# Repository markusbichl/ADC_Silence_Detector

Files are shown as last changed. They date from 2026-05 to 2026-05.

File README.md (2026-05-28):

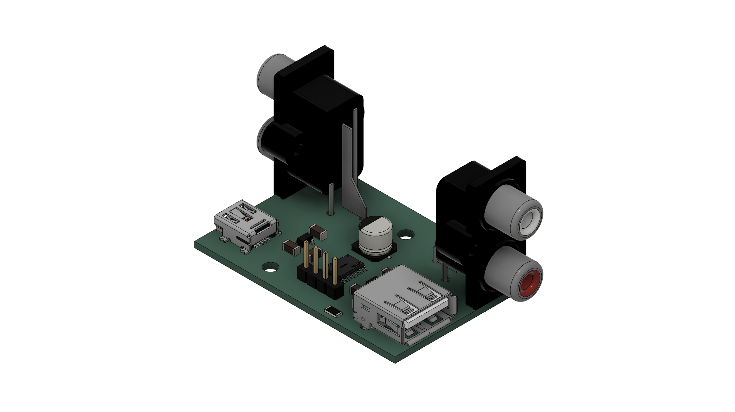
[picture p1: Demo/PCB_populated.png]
PCB populated render ADC Silence Detector PCB populated rendered


# ADC Silence Detector

A compact embedded device that monitors analog audio input and automatically cuts power to a downstream USB ADC when silence is detected - eliminating idle noise and unnecessary power draw.

---

## Overview

The ADC Silence Detector sits inline between your audio source and your USB ADC. It continuously monitors the analog audio signal on both left and right channels. As long as audio is present, the USB-A output port stays powered. Once silence is sustained, the device cuts USB power to the connected ADC, effectively turning it off without any manual intervention.

When audio resumes, power is restored and the downstream ADC comes back on automatically.

---

## Hardware

### Connectors

| Port | Type | Function |
|---|---|---|
| Power In | Mini-USB | 5 V power supply input |
| Audio In/Out L | RCA (double) | Left channel analog passthrough |
| Audio In/Out R | RCA (double) | Right channel analog passthrough |
| Power Out | USB-A | Switched 5 V output for the controlled ADC |

### Signal Path

```
Audio Source ──► RCA In (L+R) ──► passthrough ──► RCA Out (L+R) ──► Downstream equipment
                      │
                      └──► ADC Level sensing (PA6 / PB0)
                                      │
                                      ▼
                              CH32X033 MCU
                                      │
                                      ▼
Mini-USB In ──────────────────► USB-A Out (switched via PB1)
```

The audio signal path is fully passive - the RCA inputs are wired straight through to the RCA outputs with no active components in the signal chain, preserving audio quality.

---

## Firmware

### Microcontroller

**WCH CH32X033** - 32-bit RISC-V (rv32imacxw) running at 48 MHz from the internal HSI oscillator.

- IDE: MounRiver Studio 2

### Detection Logic

The firmware polls both ADC channels every 500 ms and takes the higher of the two readings as the current audio level. A hysteresis comparator prevents rapid toggling around the threshold:

| Condition | 12-bit ADC value | Action |
|---|---|---|
| Output OFF, level rises above | 20 | Turn USB-A output **ON** |
| Output ON, level falls below | 10 | Turn USB-A output **OFF** |

**ADC channels:**

| Pin | ADC Channel | Signal |
|-----|---|---|
| PA6 | CH6 | Left channel level |
| PB0 | CH8 | Right channel level |

**Output pin:** PB1 drives the USB-A power switch.

### Source Layout

```
SW
  User/
    main.c                      - application logic (ADC poll loop, hysteresis, GPIO control)
    system_ch32x035.c           - clock initialisation
    ch32x035_it.c               - interrupt handlers (unused stubs)
  Core/
    core_riscv.c/h              - RISC-V core support
  Debug/
    debug.c/h                   - SDI printf (debug UART over single wire)
  Peripheral/
    src/  inc/                  - WCH standard peripheral library
  Startup/
    startup_ch32x035.S          - reset vector and startup code
  Ld/
    Link.ld                     - linker script
PCB/
  ADC_Silence_detecor.kicad_pcb - KiCAD PCB
  ADC_Silence_detecor.kicad_sch - KiCAD Schematic
  jlcpcb/                       - Gerber files
CAD/
  case.stl                      - STL file of a simple Case
  ADC_Silence_detector.step     - STEP file of the populated PCB
  ADC_Silence_detector.stl      - STL file of the populated PCB
Demo
  ADC_Silence_detector.jpg      - Photo of the finished build
  PCB_populated.png             - Rendering of the populated PCB
```

---

## Building & Flashing

1. Open the project in **MounRiver Studio 2**.
2. Select the `obj` build configuration and click **Build** (or press `Ctrl+B`).
3. Connect a WCH-Link programmer to the SWD/SDI header.
4. Click **Download** to flash the `.hex` to the CH32X033.

Debug output is available over SDI (single-wire debug interface) at 115200 baud and prints the raw ADC level on every poll cycle.

---

## License

Peripheral library files are copyright Nanjing Qinheng Microelectronics Co., Ltd. Application code is released under the same terms - see individual file headers for details.

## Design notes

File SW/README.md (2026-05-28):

# ADC Silence Detector

A compact embedded device that monitors analog audio input and automatically cuts power to a downstream USB ADC when silence is detected — eliminating idle noise and unnecessary power draw.

---

## Overview

The ADC Silence Detector sits inline between your audio source and your USB ADC. It continuously monitors the analog audio signal on both left and right channels. As long as audio is present, the USB-A output port stays powered. Once silence is sustained, the device cuts USB power to the connected ADC, effectively turning it off without any manual intervention.

When audio resumes, power is restored and the downstream ADC comes back on automatically.

---

## Hardware

### Connectors

| Port | Type | Function |
|---|---|---|
| Power In | Mini-USB | 5 V power supply input |
| Audio In/Out L | RCA (double) | Left channel analog passthrough |
| Audio In/Out R | RCA (double) | Right channel analog passthrough |
| Power Out | USB-A | Switched 5 V output for the controlled ADC |

### Signal Path

```
Audio Source ──► RCA In (L+R) ──► passthrough ──► RCA Out (L+R) ──► Downstream equipment
                      │
                      └──► Level sensing (PA6 / PB0)
                                      │
                                      ▼
                              CH32X035 MCU
                                      │
                                      ▼
Mini-USB In ──────────────────► USB-A Out (switched via PB1)
```

The audio signal path is fully passive — the RCA inputs are wired straight through to the RCA outputs with no active components in the signal chain, preserving audio quality.

---

## Firmware

### Microcontroller

**WCH CH32X035** — 32-bit RISC-V (rv32imacxw) running at 48 MHz from the internal HSI oscillator.

- Flash: 62 KB available / ~7.5 KB used
- RAM: 20 KB available / ~160 B used
- Toolchain: riscv-none-embed GCC 8.2.0
- IDE: MounRiver Studio 2

### Detection Logic

The firmware polls both ADC channels every 500 ms and takes the higher of the two readings as the current audio level. A hysteresis comparator prevents rapid toggling around the threshold:

| Condition | 12-bit ADC value | Action |
|---|---|---|
| Output OFF, level rises above | 150 | Turn USB-A output **ON** |
| Output ON, level falls below | 100 | Turn USB-A output **OFF** |

**ADC channels:**

| Pin | ADC Channel | Signal |
|-----|---|---|
| PA6 | CH6 | Left channel level |
| PB0 | CH8 | Right channel level |

**Output pin:** PB1 (push-pull, 50 MHz) drives the USB-A power switch.

### Source Layout

```
User/
  main.c              — application logic (ADC poll loop, hysteresis, GPIO control)
  system_ch32x035.c   — clock initialisation
  ch32x035_it.c       — interrupt handlers (unused stubs)
Core/
  core_riscv.c/h      — RISC-V core support
Debug/
  debug.c/h           — SDI printf (debug UART over single wire)
Peripheral/
  src/  inc/          — WCH standard peripheral library
Startup/
  startup_ch32x035.S  — reset vector and startup code
Ld/
  Link.ld             — linker script
```

---

## Building & Flashing

1. Open the project in **MounRiver Studio 2**.
2. Select the `obj` build configuration and click **Build** (or press `Ctrl+B`).
3. Connect a WCH-Link programmer to the SWD/SDI header.
4. Click **Download** to flash the `.hex` to the CH32X035.

Debug output is available over SDI (single-wire debug interface) at 115200 baud and prints the raw ADC level on every 500 ms poll cycle.

---

## License

Peripheral library files are copyright Nanjing Qinheng Microelectronics Co., Ltd. Application code is released under the same terms — see individual file headers for details.

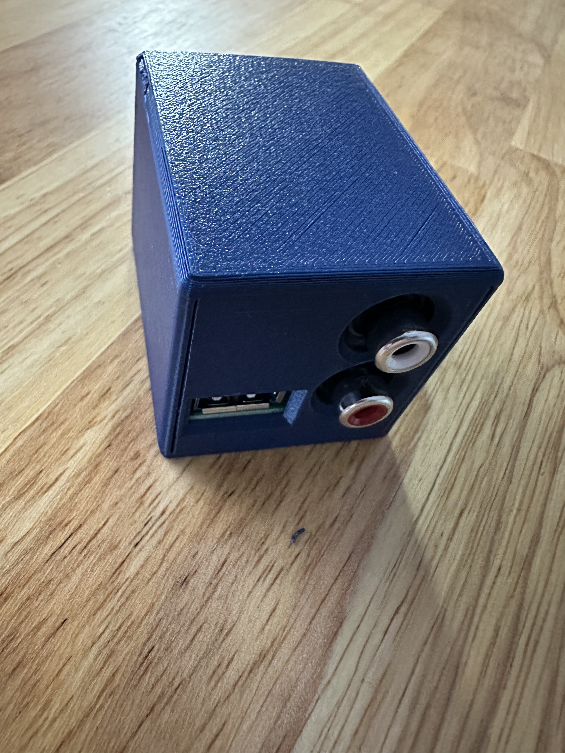
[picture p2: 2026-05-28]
Demo/ADC_Silence_detector.jpg

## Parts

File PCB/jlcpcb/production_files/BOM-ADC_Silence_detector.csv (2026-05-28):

Comment | Designator | Footprint | LCSC | Quantity
100n | C3 | C_1206_3216Metric_Pad1.33x1.80mm_HandSolder |  | 1
1u | C2 | C_1206_3216Metric_Pad1.33x1.80mm_HandSolder |  | 1
Conn_01x04_Pin | J4 | PinHeader_1x04_P2.54mm_Vertical |  | 1
USB_A | J5 | USB_A_Connfly_DS1095 |  | 1
USB_B_Mini | J3 | USB_Mini-B_Wuerth_65100516121_Horizontal |  | 1
10k | R1 | R_1206_3216Metric_Pad1.30x1.75mm_HandSolder |  | 1
~ | U1 | TSSOP-20_L6.5-W4.4-P0.65-LS6.4-BL |  | 1
1u | C1 | C_1206_3216Metric_Pad1.33x1.80mm_HandSolder |  | 1
AP2112K-3.3 | U2 | SOT-23-5_HandSoldering |  | 1
Conn_Coaxial_x2 | J2 | BNC_Win_364A2x95_Horizontal |  | 1
Conn_Coaxial_x2 | J1 | BNC_Win_364A2x95_Horizontal |  | 1
AP22804AW5 | U3 | SOT-23-5 |  | 1
120u | C6 | CP_Elec_6.3x5.8 |  | 1
100n | C5 | C_1206_3216Metric_Pad1.33x1.80mm_HandSolder |  | 1
1u | C4 | C_1206_3216Metric_Pad1.33x1.80mm_HandSolder |  | 1

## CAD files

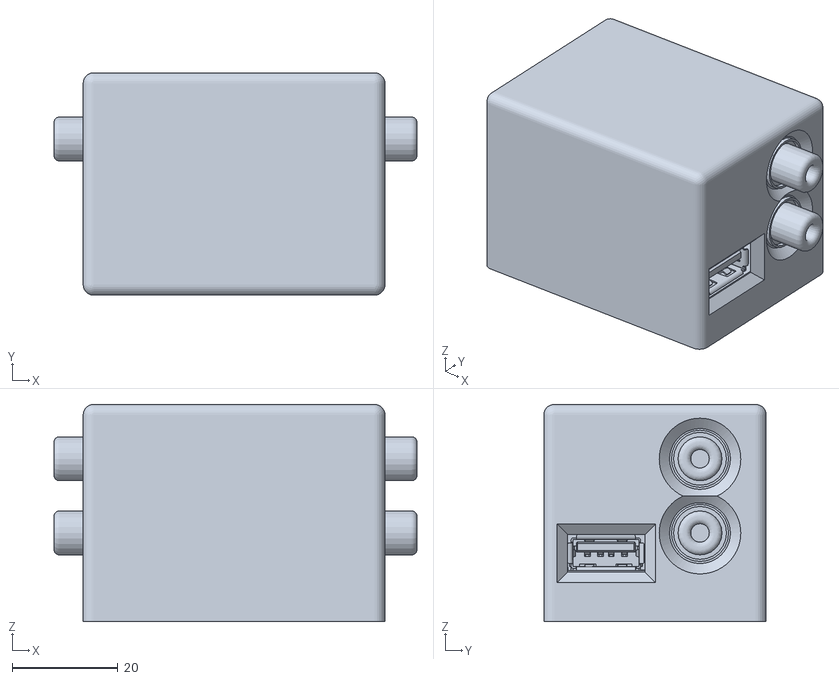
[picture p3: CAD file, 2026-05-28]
CAD/case.stl
68.5 x 42.0 x 41.0

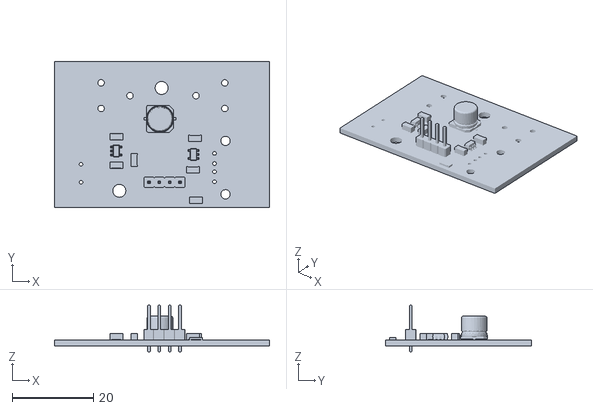
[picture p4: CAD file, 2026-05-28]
PCB/.stl
52.9 x 35.9 x 11.5

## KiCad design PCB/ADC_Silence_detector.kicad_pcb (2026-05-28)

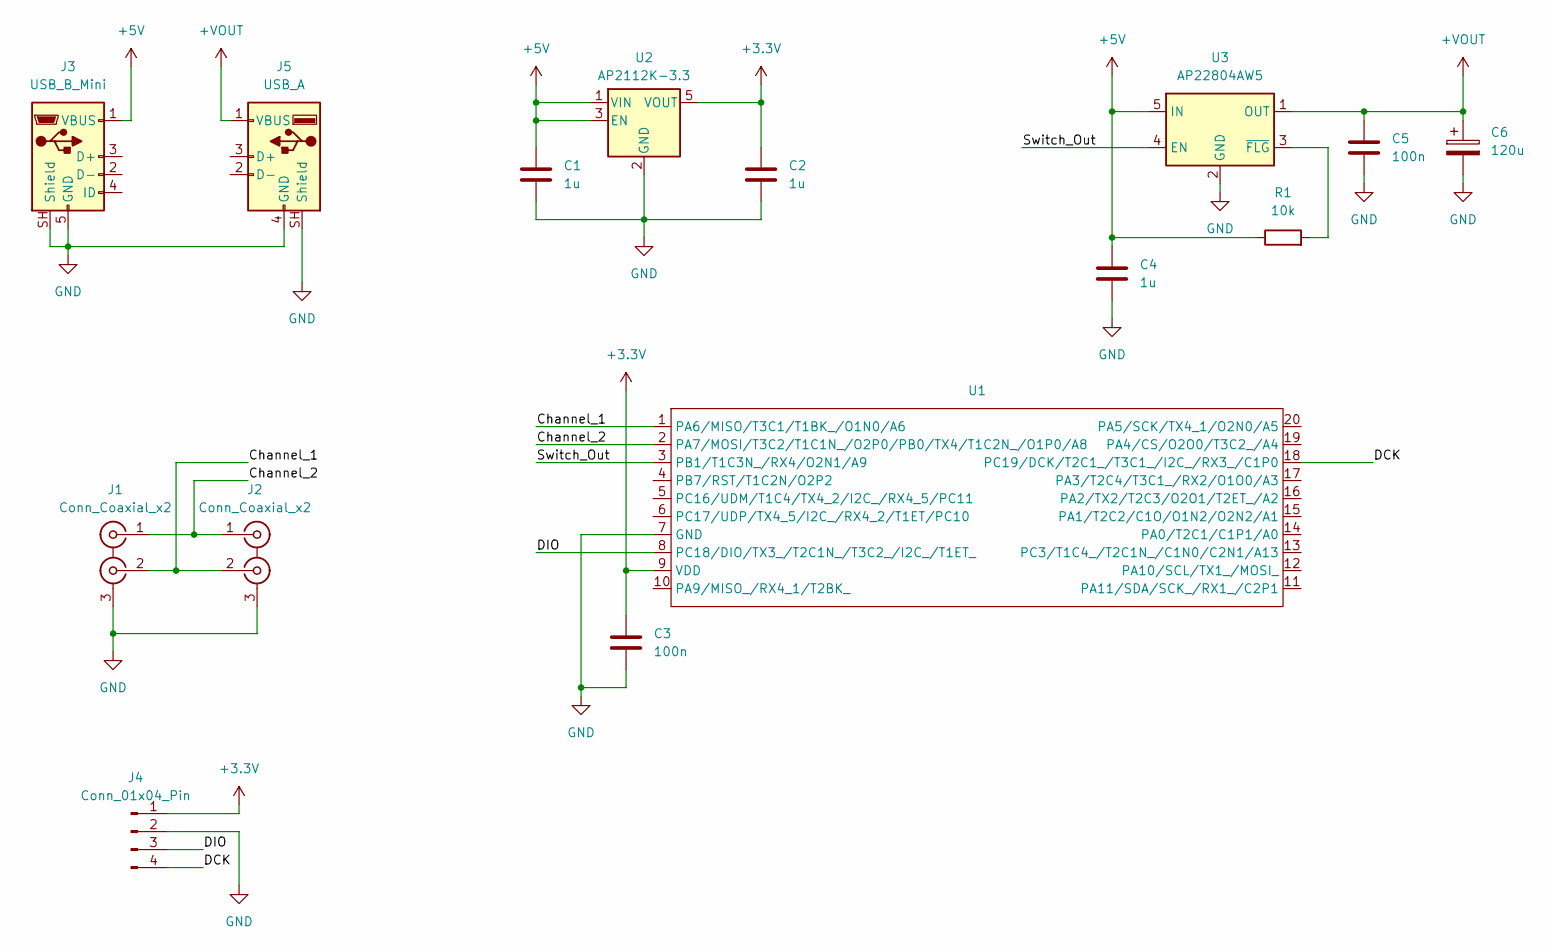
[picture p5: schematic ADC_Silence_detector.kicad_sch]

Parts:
C1, C2, C4: 1u; C_1206_3216Metric_Pad1.33x1.80mm_HandSolder
C3, C5: 100n; C_1206_3216Metric_Pad1.33x1.80mm_HandSolder
C6: 120u; CP_Elec_6.3x5.8
J1, J2: Conn_Coaxial_x2; BNC_Win_364A2x95_Horizontal
J3: USB_B_Mini; USB_Mini-B_Wuerth_65100516121_Horizontal
J4: Conn_01x04_Pin; PinHeader_1x04_P2.54mm_Vertical
J5: USB_A; USB_A_Connfly_DS1095
R1: 10k; R_1206_3216Metric_Pad1.30x1.75mm_HandSolder
U1: TSSOP-20_L6.5-W4.4-P0.65-LS6.4-BL; Manufacturer Part CH32X033F8P6; LCSC Part Name CH32X033F8P6
U2: AP2112K-3.3; SOT-23-5_HandSoldering
U3: AP22804AW5; SOT-23-5

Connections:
+3.3V: C2.1, C3.1, J4.1, U1.9 (VDD), U2.5 (VOUT)
+5V: C1.1, C4.1, J3.1 (VBUS), R1.1, U2.1 (VIN), U2.3 (EN), U3.5 (IN)
+VOUT: C5.1, C6.1, J5.1 (VBUS), U3.1 (OUT)
/Channel_1: J1.2 (IN2), J2.2 (IN2), U1.1 (PA6/MISO/T3C1/T1BK_/O1N0/A6)
/Channel_2: J1.1 (IN1), J2.1 (IN1), U1.2 (PA7/MOSI/T3C2/T1C1N_/O2P0/PB0/TX4/T1C2N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)
/DCK: J4.4, U1.18 (PC19/DCK/T2C1_/T3C1_/I2C_/RX3_/C1P0)
/DIO: J4.3, U1.8 (PC18/DIO/TX3_/T2C1N_/T3C2_/I2C_/T1ET_)
/Switch_Out: U1.3 (PB1/T1C3N_/RX4/O2N1/A9), U3.4 (EN)
GND: C1.2, C2.2, C3.2, C4.2, C5.2, C6.2, J1.3 (EXT), J2.3 (EXT), J3.5 (GND), J3.SH (Shield), J4.2, J5.4 (GND), J5.SH (Shield), U1.7 (GND), U2.2 (GND), U3.2 (GND)
unnamed: R1.2, U3.3 (~FLG)

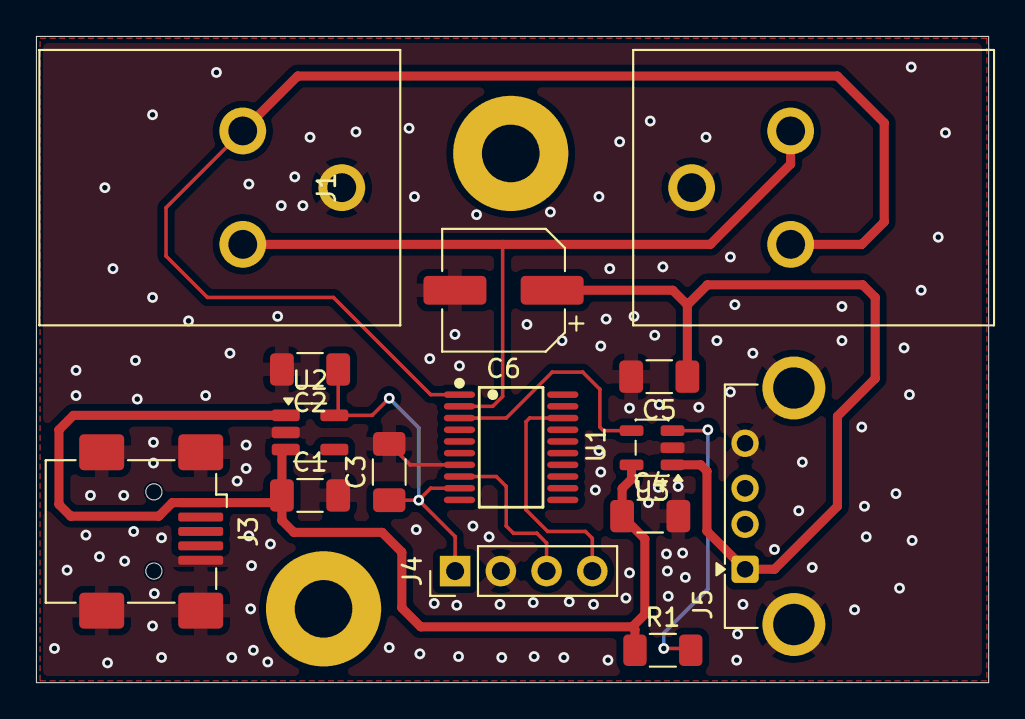
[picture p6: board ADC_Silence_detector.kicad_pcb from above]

Board: 2 copper layers, 52.9 x 35.9 mm, 17 parts (0 on the bottom side), 10 nets.

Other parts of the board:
MH1, MH2: MountingHole_3.2mm_M3_Pad

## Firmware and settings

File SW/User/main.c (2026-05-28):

/********************************** (C) COPYRIGHT *******************************
 * File Name          : main.c
 * Description        : ADC Silence Detector with corrected hysteresis.
*********************************************************************************/

/*
 *@Note
 * PB1 push-pull output (silence detector output, active high).
 * PA6 / ADC_IN6  and  PB0 / ADC_IN8  are the two analog inputs.
 *
 * State machine:
 *   - Loud and changing  -> count up to ON
 *   - Quiet              -> count down to OFF
 *   - Loud but stuck     -> count up to OFF (assume source died with DC offset)
 *   - Dead-band          -> hold current state, hold debounce counters
 */

#include "debug.h"
#include "ch32x035.h"
#include <stdbool.h>
#include <stdint.h>

/* ---- Tunables ---------------------------------------------------------- */

#define SAMPLETIME          100

#define THRESHOLD_HYST_OFF  10      /* below this = silence  */
#define THRESHOLD_HYST_ON   20      /* above this = sound    */
#define STUCK_TOL            4      /* +/- jitter tolerance for "stuck" */

/* Debounce in tick iterations (one tick = one main-loop pass ~= 300 ms) */
#define OFFCNT              10
#define ONCNT                3
#define IRREGULARCNT         5

/* Peak-hold: how many ADC samples per tick.
 * Audio is AC, so a single sample isn't a meaningful "volume". We take the
 * peak over a burst at each tick. Tune to cover the lowest audio period
 * you care about (e.g. for ~50 Hz, you want a window > 20 ms).
 */
#define PEAK_SAMPLES       256


/* ---- ADC --------------------------------------------------------------- */

void ADC_init(void)
{
    ADC_InitTypeDef  ADC_InitStructure  = {0};
    GPIO_InitTypeDef GPIO_InitStructure = {0};

    RCC_APB2PeriphClockCmd(RCC_APB2Periph_GPIOA | RCC_APB2Periph_GPIOB, ENABLE);
    RCC_APB2PeriphClockCmd(RCC_APB2Periph_ADC1, ENABLE);

    /* PA6 -> ADC_IN6 */
    GPIO_InitStructure.GPIO_Pin  = GPIO_Pin_6;
    GPIO_InitStructure.GPIO_Mode = GPIO_Mode_AIN;
    GPIO_Init(GPIOA, &GPIO_InitStructure);

    /* PB0 -> ADC_IN8 */
    GPIO_InitStructure.GPIO_Pin  = GPIO_Pin_0;
    GPIO_InitStructure.GPIO_Mode = GPIO_Mode_AIN;
    GPIO_Init(GPIOB, &GPIO_InitStructure);

    ADC_DeInit(ADC1);
    ADC_CLKConfig(ADC1, ADC_CLK_Div6);

    ADC_InitStructure.ADC_Mode               = ADC_Mode_Independent;
    ADC_InitStructure.ADC_ScanConvMode       = DISABLE;
    ADC_InitStructure.ADC_ContinuousConvMode = DISABLE;
    ADC_InitStructure.ADC_ExternalTrigConv   = ADC_ExternalTrigConv_None;
    ADC_InitStructure.ADC_DataAlign          = ADC_DataAlign_Right;
    ADC_InitStructure.ADC_NbrOfChannel       = 1;
    ADC_Init(ADC1, &ADC_InitStructure);

    ADC_Cmd(ADC1, ENABLE);
}

uint16_t ADC_read(uint8_t channel)
{
    ADC_RegularChannelConfig(ADC1, channel, 1, ADC_SampleTime_11Cycles);
    ADC_SoftwareStartConvCmd(ADC1, ENABLE);
    while (!ADC_GetFlagStatus(ADC1, ADC_FLAG_EOC));
    return ADC_GetConversionValue(ADC1);
}

/* Peak-hold over both channels for one tick. */
static uint16_t read_volume_peak(void)
{
    uint16_t peak = 0;
    for (uint16_t i = 0; i < PEAK_SAMPLES; i++) {
        uint16_t s1 = ADC_read(ADC_Channel_6);
        uint16_t s2 = ADC_read(ADC_Channel_8);
        uint16_t s  = (s1 > s2) ? s1 : s2;
        if (s > peak) peak = s;
    }
    return peak;
}


/* ---- GPIO -------------------------------------------------------------- */

void GPIO_init(void)
{
    GPIO_InitTypeDef GPIO_InitStructure = {0};

    RCC_APB2PeriphClockCmd(RCC_APB2Periph_GPIOB, ENABLE);
    GPIO_InitStructure.GPIO_Pin   = GPIO_Pin_1;
    GPIO_InitStructure.GPIO_Mode  = GPIO_Mode_Out_PP;
    GPIO_InitStructure.GPIO_Speed = GPIO_Speed_50MHz;
    GPIO_Init(GPIOB, &GPIO_InitStructure);
}


/* ---- main -------------------------------------------------------------- */

int main(void)
{
    uint16_t volume        = 0;
    uint16_t volume_old    = 0;
    uint8_t  irregularcntr = IRREGULARCNT;
    uint8_t  offcntr       = OFFCNT;
    uint8_t  oncntr        = ONCNT;
    bool     output        = Bit_RESET;

    NVIC_PriorityGroupConfig(NVIC_PriorityGroup_1);
    SystemCoreClockUpdate();
    Delay_Init();
    /*SDI_Printf_Enable();
    printf("SDI print enabled\r\n");
    printf("SystemClk:%d\r\n", SystemCoreClock);
    printf("ChipID:%08x\r\n", DBGMCU_GetCHIPID());
    printf("ADC Silence Detector\r\n");*/

    ADC_init();
    GPIO_init();
    GPIO_WriteBit(GPIOB, GPIO_Pin_1, output);

    while (1)
    {
        Delay_Ms(SAMPLETIME);

        volume = read_volume_peak();

        int16_t diff  = (int16_t)volume - (int16_t)volume_old;
        bool    stuck = (diff > -STUCK_TOL) && (diff < STUCK_TOL);

        /* -- Irregular: output is on, signal loud but not changing.
         *    Assume the source died with a stuck DC level; fall back to off. */
        if (volume > THRESHOLD_HYST_ON && stuck)
        {
                offcntr = OFFCNT;
                oncntr  = ONCNT;
            if (--irregularcntr == 0) {
                output        = Bit_RESET;
                irregularcntr = IRREGULARCNT;
                GPIO_WriteBit(GPIOB, GPIO_Pin_1, output);
            }
        }
        /* -- Rising: output off and signal above the on-threshold.
         *    Count toward ON; keep irregular and off counters armed. */
        else if (volume > THRESHOLD_HYST_ON && !stuck)
        {
            irregularcntr = IRREGULARCNT;
            offcntr       = OFFCNT;
            if (--oncntr == 0) {
                output = Bit_SET;
                oncntr = ONCNT;
                GPIO_WriteBit(GPIOB, GPIO_Pin_1, output);
            }
        }
        /* -- Falling: output on and signal below the off-threshold.
         *    Count toward OFF; keep irregular and on counters armed. */
        else if (volume < THRESHOLD_HYST_OFF)
        {
            irregularcntr = IRREGULARCNT;
            oncntr        = ONCNT;
            if (--offcntr == 0) {
                output  = Bit_RESET;
                offcntr = OFFCNT;
                GPIO_WriteBit(GPIOB, GPIO_Pin_1, output);
            }
        }
        /* -- Dead-band or no condition met. Reset irregular but preserve
         *    on/off debounce so brief excursions don't restart counting. */
        else
        {
            irregularcntr = IRREGULARCNT;
        }

        volume_old = volume;

        /*printf("vol=%4u  out=%u  on=%u off=%u irr=%u\r\n",
               volume, output, oncntr, offcntr, irregularcntr);*/
    }
}

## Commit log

2026-05-28 Fixed hysteresis, added timeouts, added pause detection
    [main.c]
2026-05-28 Added PCB, CAD and Demo
    [.stl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]
